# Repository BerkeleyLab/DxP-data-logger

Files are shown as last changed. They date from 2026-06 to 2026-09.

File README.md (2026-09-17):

# DxP Data Logger Hardware (LoRa + Distributed Sensor Probes Interface)

This repository only contains the hardware for the DxP (Distributed sensor Profiling) data logger (i.e., the “logger / base station” main board that connects to a DxP sensor probe via a connector.

The sensor probe / sensor-array board designs for DxP probes are released in a separate repository: **[DxP Sensor Probes](https://github.com/BerkeleyLab/DxP-sensor-probes)**.

The firmware for the nRF52832 is released in a separate repository: **[DxP Firmware](https://github.com/BerkeleyLab/DxP-firmware)**.

---

## Hardware overview
Designed for low-power, distributed environmental sensing deployments using the system concept from:
- *Wielandt et al., “TDD LoRa and Delta Encoding in Low-Power Networks of Environmental Sensor Arrays for Temperature and Deformation Monitoring”* (2023)

**Main logger board capabilities:**
- **LoRa modem:** RFM95W (single-channel LoRa)
- **Wireless SoC:** Nordic **nRF52832** (BLE capable)
- **Timekeeping:** **PCF2129AT** RTC
- **On-board storage:** **4 MB SPI flash** (data buffering)
- **Power:** designed for **2× AA** operation (1.8 V – 3.6 V range); includes **load switching** (e.g., TPS22919) to reduce sleep power
- **Sensor/probe interface:** **I2C** to connect to distributed sensor probes (supports long arrays through an address bit shift register on the sensor probe).
- **Micro SD card slot with load switch** for extra storage (e.g., large sensor datasets) and/or for base-station workflows to store data from multiple devices in the network.

---

## Repository contents

### KiCad design files (schematic / PCB)
- `loggerhw_v5.0.sch`
- `loggerhw_v5.0.kicad_pcb`
- `loggerhw_v5.0.kicad_pro`
- `loggerhw_v5.0.kicad_prl`
- `loggerhw_v5.0.pro`

### KiCad libraries
- `symbol/`
- `footprints/`
- `fp-lib-table`
- `fp-info-cache/`
- `sym-lib-table`
- `loggerhw_v5.0-cache.lib`

### Production / fabrication exports
- `fab/`

### Documentation
- `README.md`
- `LICENSE.md`
- `users.md`

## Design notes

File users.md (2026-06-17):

# Users / Deployments (self-reported) — DxP Data Logger Hardware

This file helps (1) estimate adoption, and (2) help the research community find others working on distributed environmental sensing.
Entries are **self-reported** and kept **non-sensitive** (no GPS coordinates).

## Add/Update your entry
Please edit this file via a PR (preferred) or open an issue: “Add me as a user”.
If you’re unsure, approximations are welcome.

## User table
| Name / Organization | First use (YYYY-MM) | Logger HW version | Boards built (approx.) | Purpose / Project description | Location (coarse) | Link (optional) | Notes |
|---|---:|---|---|---|---|---|---|
| Lawrence Berkeley National Laboratory | 2019-09 | v3.0 | 100 | Subsurface temperature monitoring | Nome/Teller, AK, USA | [https://ngee-arctic.ornl.gov](https://ngee-arctic.ornl.gov) ||
| Lawrence Berkeley National Laboratory | 2019-09 | v3.0 | 100 | Subsurface temperature monitoring | Crested Butte, CO, USA | [https://watershed.lbl.gov](https://watershed.lbl.gov) ||
| Lawrence Berkeley National Laboratory | 2020-09 | v3.0 | 100 | Snow pack temperature monitoring | Nome/Teller, AK, USA | [https://ngee-arctic.ornl.gov](https://ngee-arctic.ornl.gov) ||
| Lawrence Berkeley National Laboratory | 2020-09 | v3.0 | 100 | Snow pack temperature monitoring | Crested Butte, CO, USA | [https://watershed.lbl.gov](https://watershed.lbl.gov) ||
| Lawrence Berkeley National Laboratory | 2022-09 | v4.2 | 100 | Snow pack temperature monitoring | Nome/Teller, AK, USA | [https://ngee-arctic.ornl.gov](https://ngee-arctic.ornl.gov) ||
| Lawrence Berkeley National Laboratory | 2022-09 | v4.2 | 100 | Slope deformation monitoring | Nome/Teller, AK, USA | [https://ngee-arctic.ornl.gov](https://ngee-arctic.ornl.gov) ||
| Lawrence Berkeley National Laboratory | 2022-09 | v4.2 | 50  | Slope deformation monitoring | Berkeley, CA, USA |  ||
| Lawrence Berkeley National Laboratory | 2023-09 | v5.0 | 100 | Wireless soil and snow pack temperature monitoring | Crested Butte, CO, USA | [https://watershed.lbl.gov](https://watershed.lbl.gov) ||
| Lawrence Berkeley National Laboratory | 2025-09 | v4.2 | 50  | Stream flow and snow pack monitoring | Crested Butte, CO, USA | [https://watershed.lbl.gov](https://watershed.lbl.gov) ||

### Definitions / Guidance
- **Boards built (approx.)**: use a range like `1-10`, `1-100`, `100+` if exact counts aren’t tracked.
- **Purpose / Project description**: e.g., snowpack monitoring, subsurface thermal profiling, soil deformation, research campaign, class/lab tests.
- **Deployment environment**: e.g., above-ground, below-ground, temperate, cold region, mountainous, permafrost region.
- **Location (coarse)**: country / state / region (no exact coordinates).

## Notes (optional)
Feel free to add 1–2 lines about lessons learned or collaborations:
- e.g., “Interested in coordinating probe-array calibration approaches.”
- e.g., “Common integration issues: connector orientation / cabling / enclosure.”

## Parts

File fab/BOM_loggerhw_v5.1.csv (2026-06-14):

Id | Designator | Package | Quantity | Designation | Supplier and ref
1 | J1 | TF-01A | 1 | Micro_SD_Card_TF-01
2 | C1,C17,C3,C20,C15,C2,C11,C13,C12,C10 | C_0402_1005Metric | 10 | 0.1uF
3 | J11,J8,J6,J5 | BK-53 | 4 | Conn_01x01_Female
4 | U9,U5 | Texas_R-PDSO-G6 | 2 | TPS22919
5 | Y1 | Crystal_SMD_2016-4Pin_2.0x1.6mm | 1 | Crystal_GND24
6 | U3 | XCVR_RFM95W-915S2 | 1 | RFM95W-915
7 | U8 | WSON-6-1EP_2x2mm_P0.65mm_EP1x1.6mm | 1 | TMP117AIDRVR
8 | R12,R9,R11,R8,R7,R5 | R_0402_1005Metric | 6 | 10K
9 | U7 | Texas_R-PDSO-G6 | 1 | SN74LVC1G175DCK
10 | R14 | R_0402_1005Metric | 1 | 470
11 | R10 | R_0402_1005Metric | 1 | 1K
12 | U6 | VSSOP-8_3.0x3.0mm_P0.65mm | 1 | TCA9803
13 | J7 | JST_PH_B2B-PH-SM4-TB_1x02-1MP_P2.00mm_Vertical | 1 | S2B-PH-SM4-TB(LF)(SN)
14 | J12 | 1x10pin ICSP 2.54mm | 1 | Conn_01x10_Male
15 | D2 | LED_0603_1608Metric | 1 | LED_BLUE
16 | U1 | SOIC-20W_7.5x12.8mm_P1.27mm | 1 | PCF2129AT
17 | J10 | JST_SH_SM06B-SRSS-TB_1x06-1MP_P1.00mm_Horizontal | 1 | PROBE
18 | R19,R13 | R_0402_1005Metric | 2 | 100
19 | R6 | R_0402_1005Metric | 1 | 470k
20 | J3,J2 | JST_SH_BM06B-SRSS-TB_1x06-1MP_P1.00mm_Vertical | 2 | Conn_01x06
21 | D3 | LED_0603_1608Metric | 1 | LED_RED
22 | C7 | C_0603_1608Metric | 1 | 10uF
23 | U2 | QFN-48-1EP_6x6mm_P0.4mm_EP4.66x4.66mm | 1 | nRF52832-QFxx
24 | J20 | U.FL_Hirose_U.FL-R-SMT-1_Vertical | 1 | U.FL-R-SMT-1
25 | C21,C9 | C_0402_1005Metric | 2 | 0.8pF C0G
26 | L2 | L_0402_1005Metric | 1 | 3.9nH
27 | C14 | C_0402_1005Metric | 1 | 1uF
28 | C6,C5 | C_0402_1005Metric | 2 | 12pF
29 | C4 | C_0402_1005Metric | 1 | 100pF
30 | U4 | SOIC-8_3.9x4.9mm_P1.27mm | 1 | MX25R3235FM1IH0

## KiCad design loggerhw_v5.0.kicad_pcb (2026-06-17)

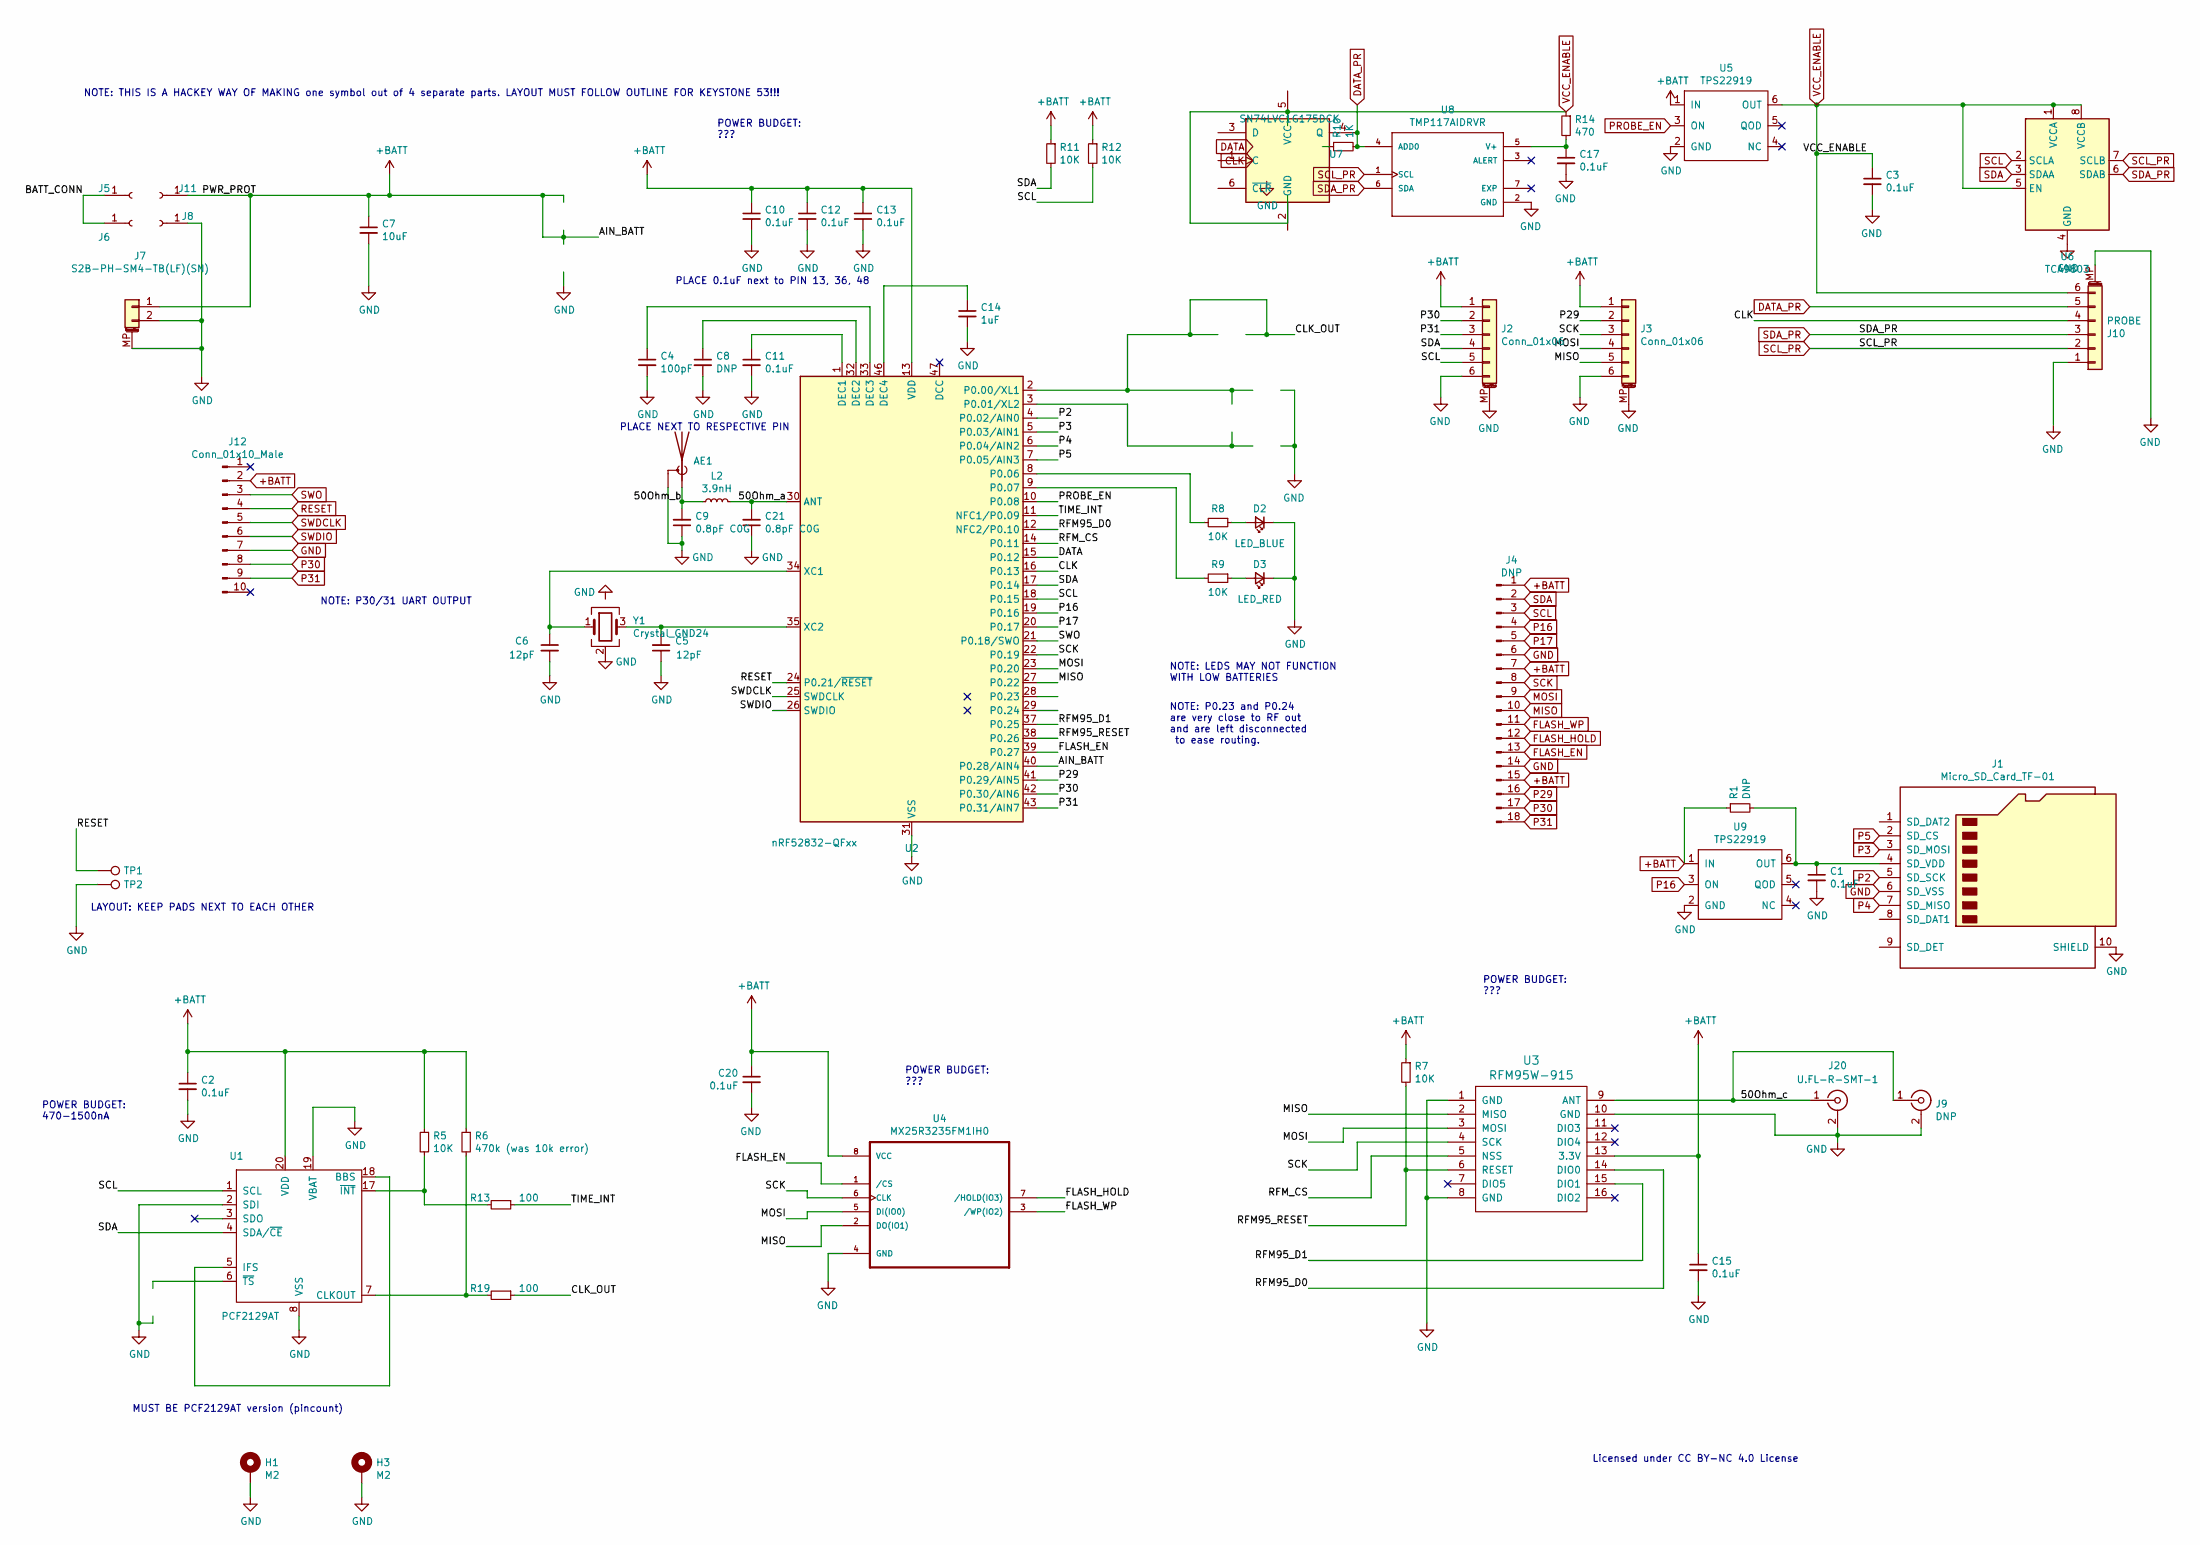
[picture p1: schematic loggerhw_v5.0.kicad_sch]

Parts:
AE1: Antenna_Shield; Texas_SWRA117D_2.4GHz_Right
C1, C2, C3, C10, C11, C12, C13, C15, C17, C20: 0.1uF; C_0402_1005Metric
C4: 100pF; C_0402_1005Metric
C5, C6: 12pF; C_0402_1005Metric
C7: 10uF; C_0603_1608Metric
C8: DNP; C_0402_1005Metric
C9, C21: 0.8pF C0G; C_0402_1005Metric
C14: 1uF; C_0402_1005Metric
D2: LED_BLUE; LED_0603_1608Metric
D3: LED_RED; LED_0603_1608Metric
H1, H3: M2; MountingHole_2.2mm_M2
J1: Micro_SD_Card_TF-01; TF-01A
J2, J3: Conn_01x06; JST_SH_BM06B-SRSS-TB_1x06-1MP_P1.00mm_Vertical
J4: DNP; PinHeader_1x18_P2.54mm_Vertical
J5, J6, J8, J11: Conn_01x01_Female; BK-53
J7: S2B-PH-SM4-TB(LF)(SN); JST_PH_B2B-PH-SM4-TB_1x02-1MP_P2.00mm_Vertical
J9: DNP; SMA_Samtec_SMA-J-P-X-ST-EM1_EdgeMount
J10: PROBE; JST_SH_SM06B-SRSS-TB_1x06-1MP_P1.00mm_Horizontal
J12: Conn_01x10_Male; 1x10pin ICSP 2.54mm
J20: U.FL-R-SMT-1; U.FL_Hirose_U.FL-R-SMT-1_Vertical
L2: 3.9nH; L_0402_1005Metric
R1: DNP; R_0402_1005Metric
R5, R7, R8, R9, R11, R12: 10K; R_0402_1005Metric
R6: 470k (was 10k error); R_0402_1005Metric
R10: 1K; R_0402_1005Metric
R13, R19: 100; R_0402_1005Metric
R14: 470; R_0402_1005Metric
TP1, TP2: TestPoint; TestPoint_Pad_D1.0mm
U1: PCF2129AT; SOIC-20W_7.5x12.8mm_P1.27mm
U2: nRF52832-QFxx; QFN-48-1EP_6x6mm_P0.4mm_EP4.66x4.66mm
U3: RFM95W-915; XCVR_RFM95W-915S2
U4: MX25R3235FM1IH0; SOIC-8_3.9x4.9mm_P1.27mm
U5, U9: TPS22919; Texas_R-PDSO-G6
U6: TCA9803; VSSOP-8_3.0x3.0mm_P0.65mm
U7: SN74LVC1G175DCK; Texas_R-PDSO-G6
U8: TMP117AIDRVR; WSON-6-1EP_2x2mm_P0.65mm_EP1x1.6mm
Y1: Crystal_GND24; Crystal_SMD_2016-4Pin_2.0x1.6mm

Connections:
+BATT: C2.1, C7.1, C10.1, C12.1, C13.1, C15.1, C20.1, J2.1, J3.1, J4.1, J4.7, J4.15, J7.1, J11.1, J12.2, R1.1, R5.1, R6.1, R7.1, R11.1, R12.1, U1.20 (VDD), U2.13 (VDD), U2.36 (VDD), U2.40 (P0.28/AIN4), U2.48 (VDD), U3.13 (3.3V), U4.8 (VCC), U5.1 (IN), U9.1 (IN)
/50Ohm_a: C21.2, L2.2, U2.30 (ANT)
/50Ohm_b: AE1.1 (A), C9.2, L2.1
/50Ohm_c: J9.1 (In), J20.1 (In), U3.9 (ANT)
/BATT_CONN: J5.1, J6.1
/CLK_OUT: R19.1, U2.2 (P0.00/XL1)
/RFM95_D0: U2.12 (NFC2/P0.10), U3.14 (DIO0)
/RFM95_D1: U2.37 (P0.25), U3.15 (DIO1)
/RFM95_RESET: R7.2, U2.38 (P0.26), U3.6 (RESET)
/RFM_CS: U2.14 (P0.11), U3.5 (NSS)
/TIME_INT: R13.1, U2.11 (NFC1/P0.09)
CLK: J10.4, U2.16 (P0.13), U7.1 (C)
DATA: U2.15 (P0.12), U7.3 (D)
FLASH_EN: J4.13, U2.39 (P0.27), U4.1 (/CS)
FLASH_HOLD: J4.12, U4.7 (/HOLD(IO3))
FLASH_WP: J4.11, U4.3 (/WP(IO2))
GND: AE1.2 (Shield), C1.2, C2.2, C3.2, C4.2, C5.1, C6.2, C7.2, C8.2, C9.1, C10.2, C11.2, C12.2, C13.2, C14.2, C15.2, C17.2, C20.2, C21.1, D2.1 (K), D3.1 (K), H1.1, H3.1, J1.6 (SD_VSS), J1.10 (SHIELD), J2.6, J2.MP (MountPin), J3.6, J3.MP (MountPin), J4.6, J4.14, J7.2, J7.MP (MountPin), J8.1, J9.2 (Ext), J10.1, J10.MP (MountPin), J12.7, J20.2 (Ext), TP2.1, U1.2 (SDI), U1.8 (VSS), U1.19 (VBAT), U2.31 (VSS), U2.45 (VSS), U2.49 (VSS), U3.1 (GND), U3.8 (GND), U3.10 (GND), U4.4 (GND), U5.2 (GND), U6.4 (GND), U7.2 (GND), U8.2 (GND), U9.2 (GND), Y1.2 (G), Y1.4 (G)
MISO: J3.5, J4.10, U2.27 (P0.22), U3.2 (MISO), U4.2 (DO(IO1))
MOSI: J3.4, J4.9, U2.23 (P0.20), U3.3 (MOSI), U4.5 (DI(IO0))
unnamed: C1.1, J1.4 (SD_VDD), R1.2, U9.6 (OUT)
unnamed: C4.1, U2.33 (DEC3)
unnamed: C5.2, U2.35 (XC2), Y1.3
unnamed: C6.1, U2.34 (XC1), Y1.1
unnamed: C8.1, U2.32 (DEC2)
unnamed: C11.1, U2.1 (DEC1)
unnamed: C14.1, U2.46 (DEC4)
unnamed: C17.1, R14.2, U8.5 (V+)
unnamed: D2.2 (A), R8.1
unnamed: D3.2 (A), R9.1
unnamed: R8.2, U2.8 (P0.06)
unnamed: R9.2, U2.9 (P0.07)
unnamed: R5.2, R13.2, U1.17 (~INT)
unnamed: R6.2, R19.2, U1.7 (CLKOUT)
unnamed: U1.5 (IFS), U1.18 (BBS)
P2: J1.5 (SD_SCK), U2.4 (P0.02/AIN0)
P3: J1.3 (SD_MOSI), U2.5 (P0.03/AIN1)
P4: J1.7 (SD_MISO), U2.6 (P0.04/AIN2)
P5: J1.2 (SD_CS), U2.7 (P0.05/AIN3)
P16: J4.4, U2.19 (P0.16), U9.3 (ON)
P17: J4.5, U2.20 (P0.17)
P29: J3.2, J4.16, U2.41 (P0.29/AIN5)
P30: J2.2, J4.17, J12.8, U2.42 (P0.30/AIN6)
P31: J2.3, J4.18, J12.9, U2.43 (P0.31/AIN7)
PROBE_EN: U2.10 (P0.08), U5.3 (ON)
RESET: J12.4, TP1.1, U2.24 (P0.21/~RESET)
SCK: J3.3, J4.8, U2.22 (P0.19), U3.4 (SCK), U4.6 (CLK)
SCL: J2.5, J4.3, R12.2, U1.1 (SCL), U2.18 (P0.15), U6.2 (SCLA)
SCL_PR: J10.2, U6.7 (SCLB), U8.1 (SCL)
SDA: J2.4, J4.2, R11.2, U1.4 (SDA/~CE), U2.17 (P0.14), U6.3 (SDAA)
SDA_PR: J10.3, U6.6 (SDAB), U8.6 (SDA)
SWDCLK: J12.5, U2.25 (SWDCLK)
SWDIO: J12.6, U2.26 (SWDIO)
SWO: J12.3, U2.21 (P0.18/SWO)
VCC_ENABLE: C3.1, J10.6, R14.1, U5.6 (OUT), U6.1 (VCCA), U6.5 (EN), U6.8 (VCCB), U7.5 (VCC), U7.6 (~CLR)

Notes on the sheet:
NOTE: THIS IS A HACKEY WAY OF MAKING one symbol out of 4 separate parts. LAYOUT MUST FOLLOW OUTLINE FOR KEYSTONE 53!!!
LAYOUT: KEEP PADS NEXT TO EACH OTHER
PLACE 0.1uF next to PIN 13, 36, 48
NOTE: P0.23 and P0.24 are very close to RF out and are left disconnected to ease routing.
NOTE: LEDS MAY NOT FUNCTION WITH LOW BATTERIES
Licensed under CC BY-NC 4.0 License
POWER BUDGET: 470-1500nA
POWER BUDGET: ???
MUST BE PCF2129AT version (pincount)
PLACE NEXT TO RESPECTIVE PIN
NOTE: P30/31 UART OUTPUT

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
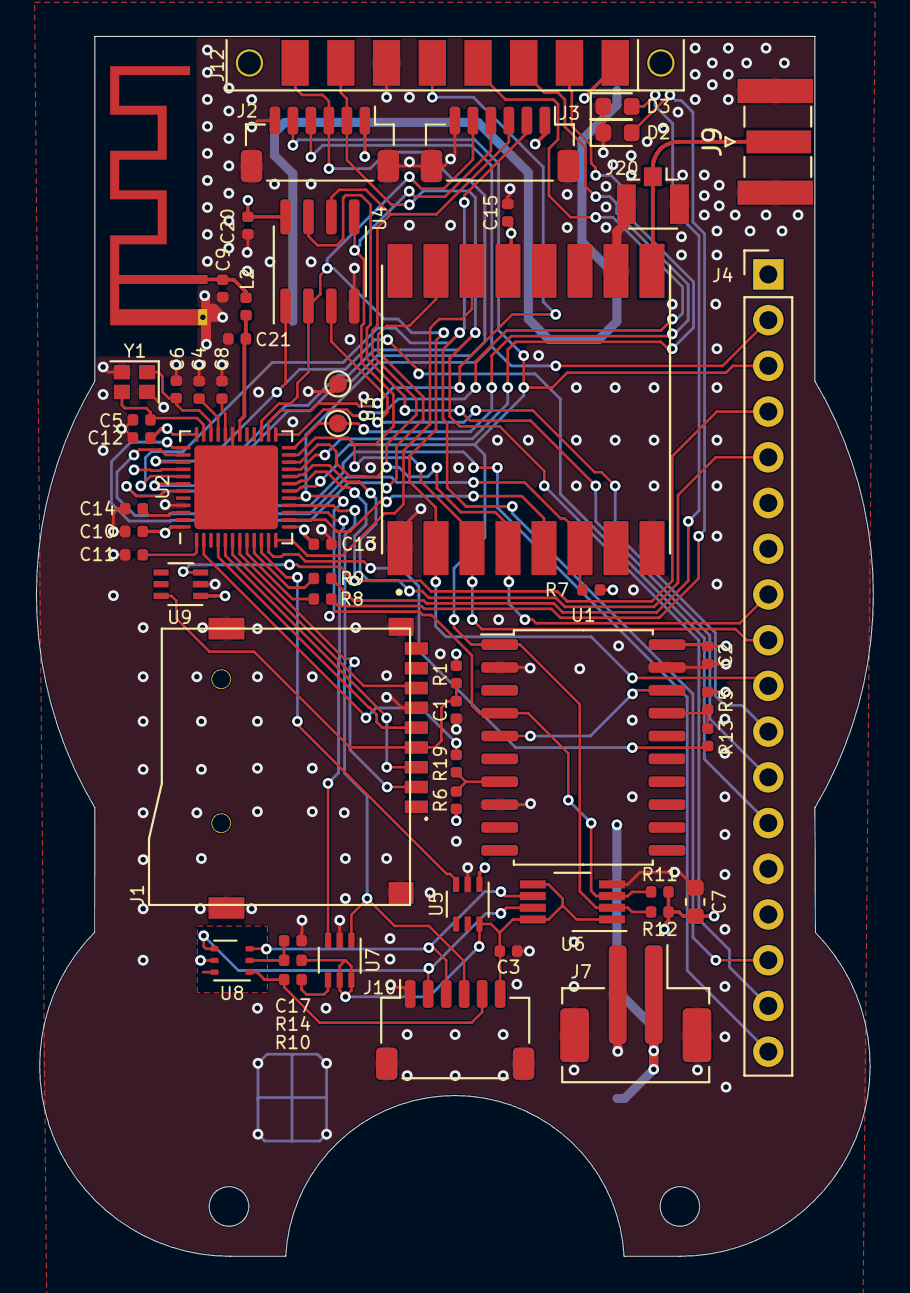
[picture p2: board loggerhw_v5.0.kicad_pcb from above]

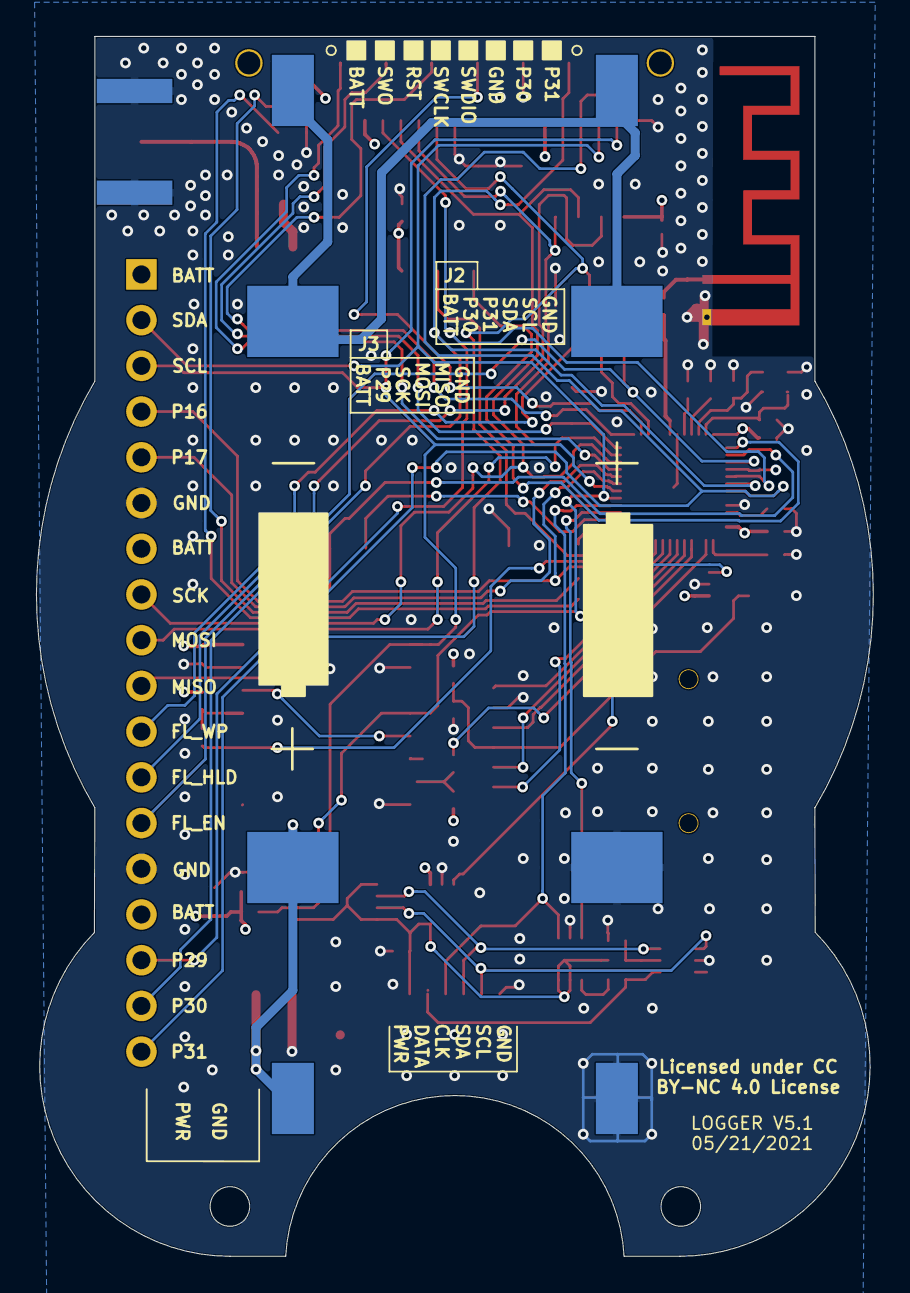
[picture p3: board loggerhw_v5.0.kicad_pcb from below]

Board: 4 copper layers, 46.5 x 67.8 mm, 61 parts (4 on the bottom side), 56 nets.

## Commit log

2026-06-13 Initial push of the DxP v4.2 KiCad project, license, README.md, users.md, libraries, and fabrication files
    [loggerhw_v4.2-B_Cu.gbl, loggerhw_v4.2-B_Mask.gbs, loggerhw_v4.2-B_Paste.gbp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]
2026-06-14 Version 5.0 added LoRa base station provisions: SD card slot with load switch, expansion header, SMA connector and general improvements
    [BOM_loggerhw_v5.1.csv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]
2026-06-17 silk screen tweak
    [loggerhw_v5.0.kicad_pcb, loggerhw_v5.0.kicad_sch]
2026-09-17 Update README with links to related repositories
    Added links to separate repositories for sensor probes and firmware.
